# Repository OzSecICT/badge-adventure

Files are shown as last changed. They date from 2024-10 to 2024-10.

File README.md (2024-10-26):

# OzSec 2024 Adventure Badge

This repo contains the code and KiCad files to design the OzSec 2024 badge. 

## Theme

The theme of this year's badge is 'Light The Badge' where the front of the badge has LEDs representing various cities. In the default mode it will be twinkly and randomly blink the LEDs. 

When you connect to the badge via a serial console, a text-based adventure RPG will be playable. Each city in the game is represented by an LED, and each city will have a quest that needs to be completed. 

Once you complete each city's quest, that LED will light up. You need to light up every city in order to unlock access to Wichita and change the RGB LED. Completing that ultimate quest will reveal a CTF flag and change the RGB LED to green. 

## Codebase

The badge is based on an ESP32-S3 using the Arduino framework. This repo is designed to be opened in VS Code with the PlatformIO extension. 

### Files

Brief overview of the files and what they do:

**include/config.hpp:**
- Tracks the currently developed version for use with updates over the web. 
- WiFi SSID and Password defaults.

**include/ozsec/update.hpp and src/ozsec/update.cpp:**
- Manages over the air updates.
- Triggered by holding boot button in `main.cpp`

**includes/ozsec/ble.hpp and src/ozsec/ble.hpp:**
- Bluetooth Low Energy config, searches for an advertisement from an OzSec 2023: S1M0N badge. Sets a variable once a badge advertisement is found and stops searching.

**includes/ozsec/lights.hpp and src/ozsec/lights.cpp:**
- Manages the LEDs and NeoPixel RGB LED
- `Lights::twinkle()` is the main function that is called by `Adventure::bgloop()` on the second core in `main.cpp` to twinkle the lights when not in the game.

**src/main.cpp:**
- Main arduino `setup()` and `loop()` functions that call other class functions. 
- Sets up buttons using the OneButton library.
- Manages persistent data and game/badge states using the Preferences library.

**includes/ozsec/buttons.hpp:**
- Centralized setup of the buttons using OneButton

**includes/ozsec/rooms.hpp:**
- Room configs for the text based adventure

**includes/ozsec/npcs.hpp:**
- NPC config for the text based adventure

**includes/ozsec/adventure.hpp and src/ozsec/adventure.cpp:**
- The main text based adventure game.
- Manages character and badge states, what lights are lit, flags unlocked, etc.

### Wi-Fi setup
You can either set the wifi credentials in `config.hpp` or you can launch into the text game and enter `wifi` command to set it on your badge specifically.

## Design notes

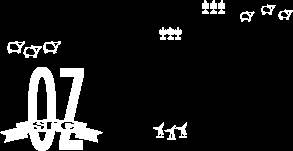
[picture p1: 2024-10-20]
kicad/ozsec-2024/Asset 7.png

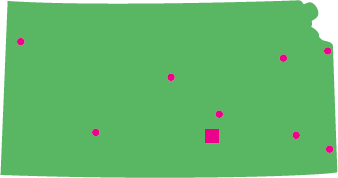
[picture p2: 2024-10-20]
kicad/ozsec-2024/LED Placement.png

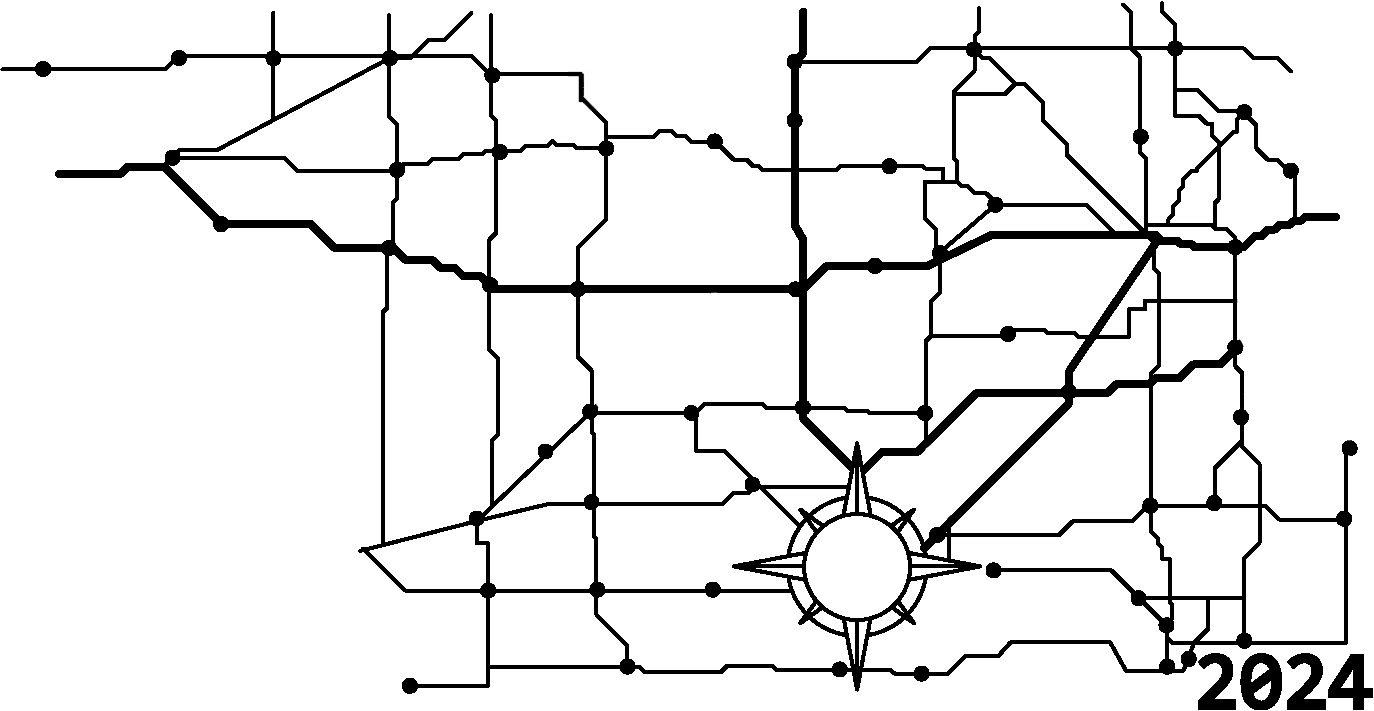
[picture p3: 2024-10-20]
kicad/ozsec-2024/Copper_Modified.png

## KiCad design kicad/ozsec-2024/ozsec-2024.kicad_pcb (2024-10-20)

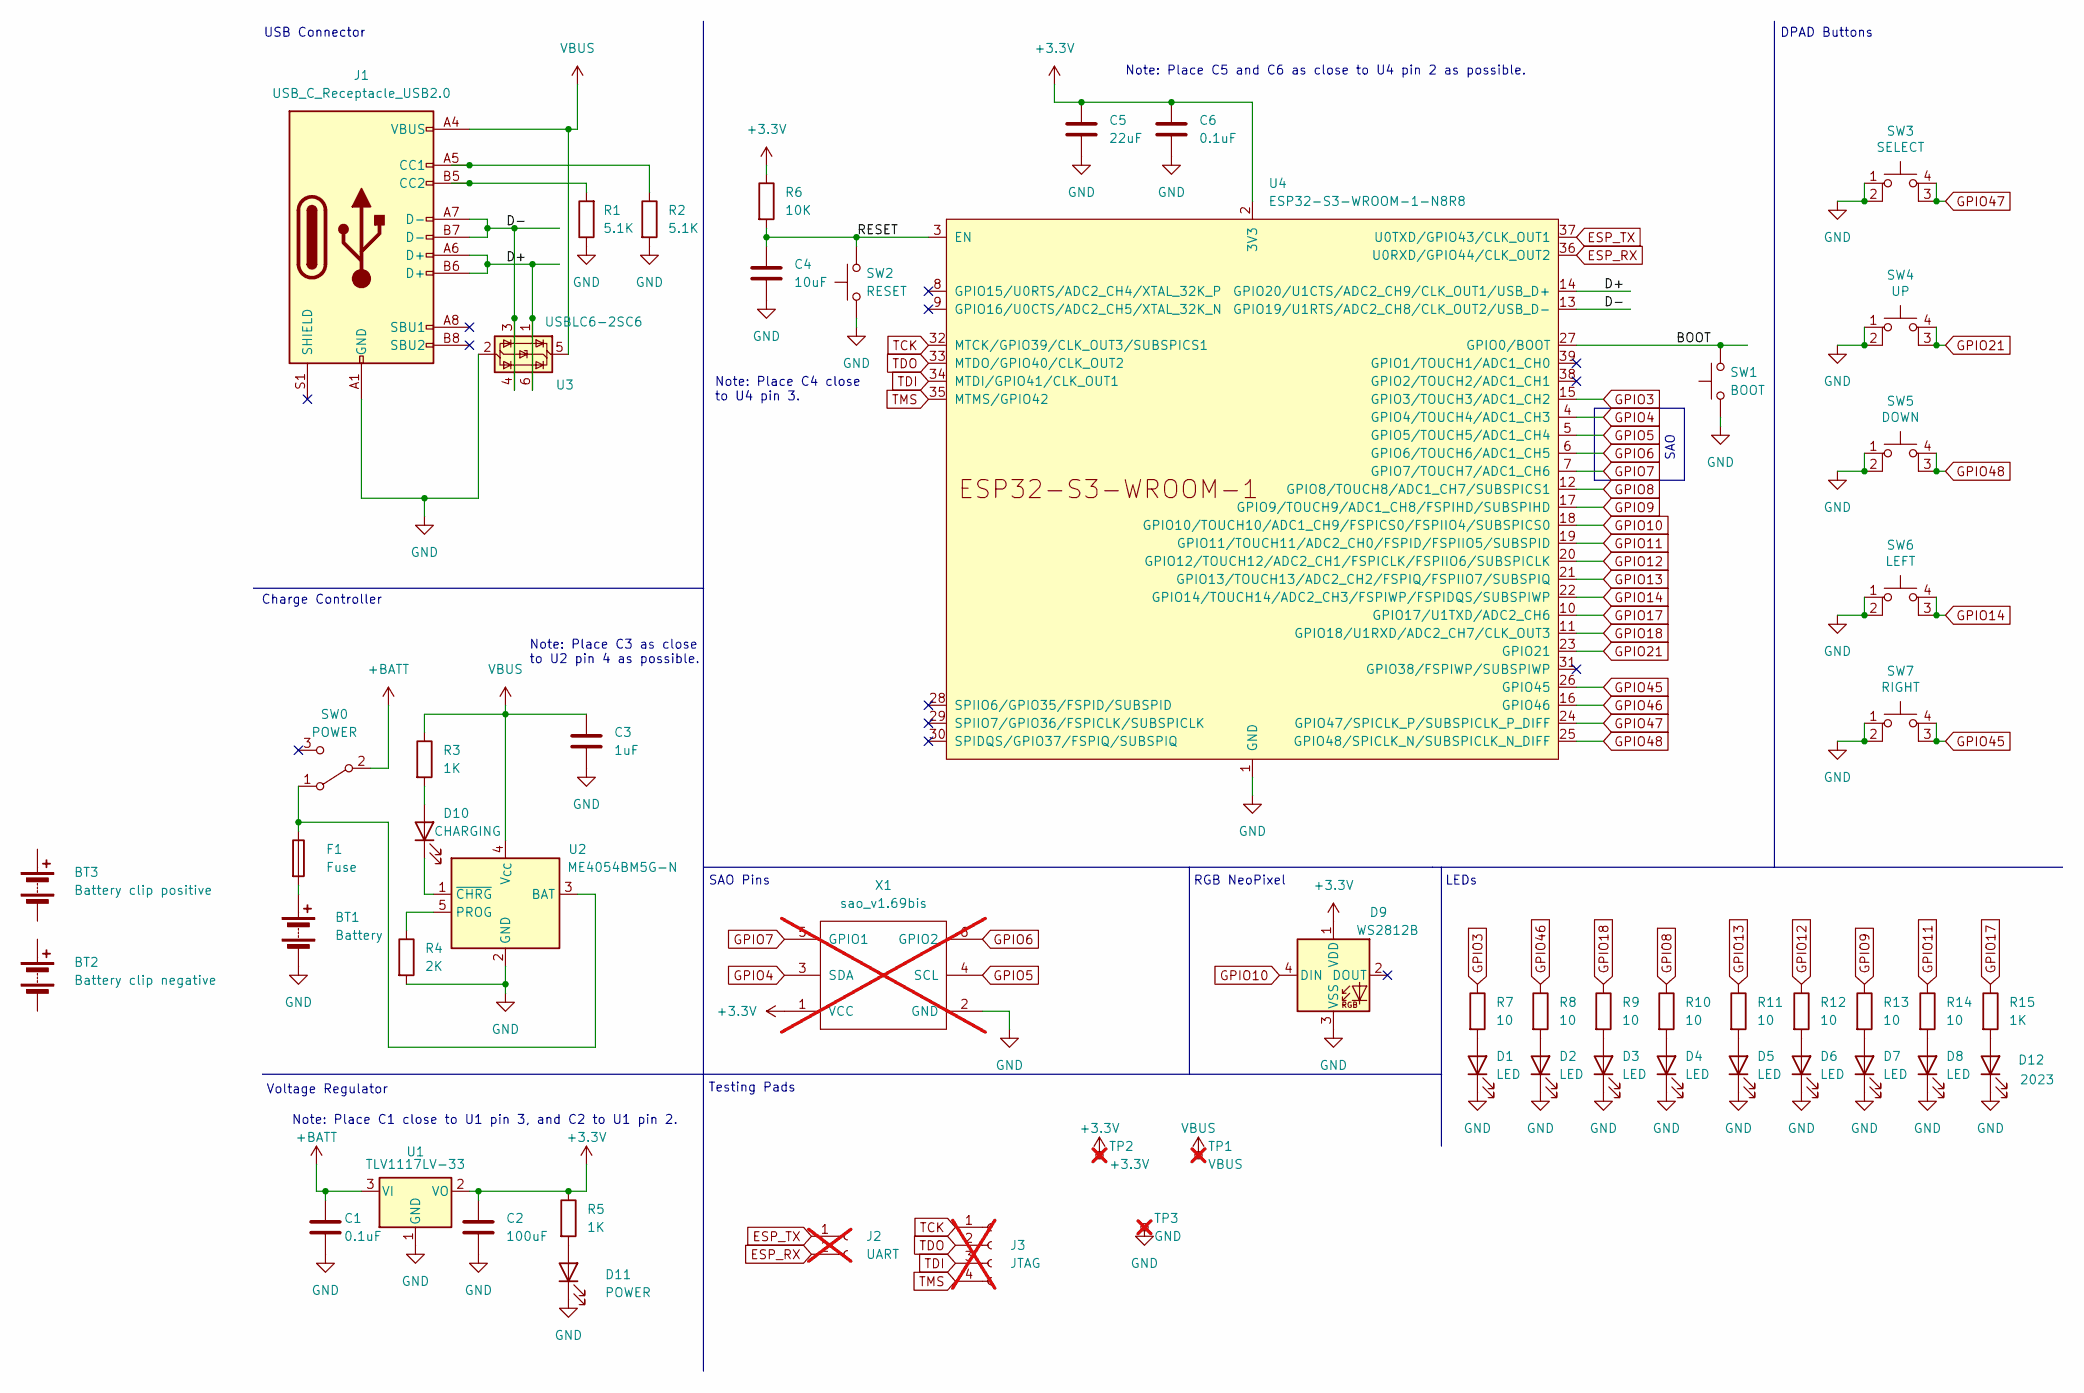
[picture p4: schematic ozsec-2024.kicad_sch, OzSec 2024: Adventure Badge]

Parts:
BT1: Battery; MY-AA-04_Silkscreen_Only; LCSC C2979179
BT2: Battery clip negative; MY-AA-04_Negative; LCSC C2979179
BT3: Battery clip positive; MY-AA-04_Positive; LCSC C2979179
C1, C6: 0.1uF; C_0402_1005Metric; LCSC C1525
C2: 100uF; C_1206_3216Metric; LCSC C15008
C3: 1uF; C_0402_1005Metric; LCSC C52923
C4: 10uF; C_0805_2012Metric; LCSC C15850
C5: 22uF; C_0805_2012Metric; LCSC C45783
D1, D2, D3, D4, D5, D6, D7, D8: LED; LED_0805_2012Metric_Pad1.15x1.40mm_HandSolder; LCSC C34499
D9: WS2812B; LED_WS2812B_PLCC4_5.0x5.0mm_P3.2mm; LCSC C2843785
D10: CHARGING; LED_0805_2012Metric_Pad1.15x1.40mm_HandSolder; LCSC C2296
D11: POWER; LED_0805_2012Metric_Pad1.15x1.40mm_HandSolder; LCSC C2297
D12: 2023; LED_0805_2012Metric_Pad1.15x1.40mm_HandSolder; LCSC C2297
F1: Fuse; Fuse_1206_3216Metric; LCSC C261957
J1: USB_C_Receptacle_USB2.0; USB_C_Receptacle_G-Switch_GT-USB-7010ASV; LCSC C2988369
J2: UART; PinHeader_1x02_P2.54mm_Vertical; not fitted
J3: JTAG; PinHeader_1x04_P2.54mm_Vertical; not fitted
R1, R2: 5.1K; R_0805_2012Metric; LCSC C27834
R3, R5, R15: 1K; R_0805_2012Metric_Pad1.20x1.40mm_HandSolder; LCSC C17513
R4: 2K; R_0805_2012Metric; LCSC C17604
R6: 10K; R_0805_2012Metric; LCSC C17414
R7, R8, R9, R10, R11, R12, R13, R14: 10; R_0805_2012Metric; LCSC C17415
SW0: POWER; SW_SPDT_PCM12; LCSC C431541
SW1: BOOT; SW_Push_1P1T_XKB_TS-1187A; LCSC C318884
SW2: RESET; SW_Push_1P1T_XKB_TS-1187A; LCSC C318884
SW3: SELECT; SW_SMD_TSC015XXXXXXX; LCSC C2888900
SW4: UP; SW_SMD_TSC015XXXXXXX; LCSC C2888900
SW5: DOWN; SW_SMD_TSC015XXXXXXX; LCSC C2888900
SW6: LEFT; SW_SMD_TSC015XXXXXXX; LCSC C2888900
SW7: RIGHT; SW_SMD_TSC015XXXXXXX; LCSC C2888900
TP1: VBUS; TestPoint_Pad_D1.5mm; not fitted
TP2: +3.3V; TestPoint_Pad_D1.5mm; not fitted
TP3: GND; TestPoint_Pad_1.5x1.5mm; not fitted
U1: TLV1117LV-33; SOT-223; LCSC C15578
U2: ME4054BM5G-N; TSOT-23-5; LCSC C478383
U3: USBLC6-2SC6; SOT-23-6; LCSC C2827654
U4: ESP32-S3-WROOM-1-N8R8; ESP32-S3-WROOM-1; LCSC C2913201
X1: sao_v1.69bis; Badgelife-SAOv169-BADGE-2x3; not fitted

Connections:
+3.3V: C2.1, C5.1, C6.1, D9.1 (VDD), R5.1, R6.1, TP2.1, U1.2 (VO), U1.4, U4.2 (3V3), X1.1 (VCC)
+BATT: C1.1, SW0.2 (B), U1.3 (VI)
/BOOT: SW1.2, U4.27 (GPIO0/BOOT)
/D+: J1.A6 (D+), J1.B6 (D+), U3.1 (I/O1), U3.6 (I/O1), U4.14 (GPIO20/U1CTS/ADC2_CH9/CLK_OUT1/USB_D+)
/D-: J1.A7 (D-), J1.B7 (D-), U3.3 (I/O2), U3.4 (I/O2), U4.13 (GPIO19/U1RTS/ADC2_CH8/CLK_OUT2/USB_D-)
/RESET: C4.1, R6.2, SW2.2, U4.3 (EN)
ESP_RX: J2.2, U4.36 (U0RXD/GPIO44/CLK_OUT2)
ESP_TX: J2.1, U4.37 (U0TXD/GPIO43/CLK_OUT1)
GND: BT1.2 (-), BT2.2 (-), C1.2, C2.2, C3.2, C4.2, C5.2, C6.2, D1.1 (K), D2.1 (K), D3.1 (K), D4.1 (K), D5.1 (K), D6.1 (K), D7.1 (K), D8.1 (K), D9.3 (VSS), D11.1 (K), D12.1 (K), J1.A1 (GND), J1.A12 (GND), J1.B1 (GND), J1.B12 (GND), R1.1, R2.2, R4.2, SW1.1, SW2.1, SW3.1, SW3.2, SW4.1, SW4.2, SW5.1, SW5.2, SW6.1, SW6.2, SW7.1, SW7.2, TP3.1, U1.1 (GND), U2.2 (GND), U3.2 (GND), U4.1 (GND), U4.40 (GND), U4.41 (GND), X1.2 (GND)
GPIO3: R7.1, U4.15 (GPIO3/TOUCH3/ADC1_CH2)
GPIO4: U4.4 (GPIO4/TOUCH4/ADC1_CH3), X1.3 (SDA)
GPIO5: U4.5 (GPIO5/TOUCH5/ADC1_CH4), X1.4 (SCL)
GPIO6: U4.6 (GPIO6/TOUCH6/ADC1_CH5), X1.6 (GPIO2)
GPIO7: U4.7 (GPIO7/TOUCH7/ADC1_CH6), X1.5 (GPIO1)
GPIO8: R10.1, U4.12 (GPIO8/TOUCH8/ADC1_CH7/SUBSPICS1)
GPIO9: R13.1, U4.17 (GPIO9/TOUCH9/ADC1_CH8/FSPIHD/SUBSPIHD)
GPIO10: D9.4 (DIN), U4.18 (GPIO10/TOUCH10/ADC1_CH9/FSPICS0/FSPIIO4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)
GPIO11: R14.1, U4.19 (GPIO11/TOUCH11/ADC2_CH0/FSPID/FSPIIO5/S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)
GPIO12: R12.1, U4.20 (GPIO12/TOUCH12/ADC2_CH1/FSPICLK/FSPIIO6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)
GPIO13: R11.1, U4.21 (GPIO13/TOUCH13/ADC2_CH2/FSPIQ/FSPIIO7/S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)
GPIO14: SW6.3 (K), SW6.4 (A), U4.22 (GPIO14/TOUCH14/ADC2_CH3/FSPIWP/FSPIDQS/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)
GPIO17: R15.1, U4.10 (GPIO17/U1TXD/ADC2_CH6)
GPIO18: R9.1, U4.11 (GPIO18/U1RXD/ADC2_CH7/CLK_OUT3)
GPIO21: SW4.3 (K), SW4.4 (A), U4.23 (GPIO21)
GPIO45: SW7.3 (K), SW7.4 (A), U4.26 (GPIO45)
GPIO46: R8.1, U4.16 (GPIO46)
GPIO47: SW3.3 (K), SW3.4 (A), U4.24 (GPIO47/SPICLK_P/SUBSPICLK_P_DIFF)
GPIO48: SW5.3 (K), SW5.4 (A), U4.25 (GPIO48/SPICLK_N/SUBSPICLK_N_DIFF)
unnamed: D1.2 (A), R7.2
unnamed: D2.2 (A), R8.2
unnamed: D3.2 (A), R9.2
unnamed: D4.2 (A), R10.2
unnamed: D5.2 (A), R11.2
unnamed: D6.2 (A), R12.2
unnamed: D7.2 (A), R13.2
unnamed: D8.2 (A), R14.2
unnamed: D10.2 (A), R3.2
unnamed: D10.1 (K), U2.1 (~CHRG)
unnamed: D11.2 (A), R5.2
unnamed: D12.2 (A), R15.2
unnamed: J1.A5 (CC1), R2.1
unnamed: J1.B5 (CC2), R1.2
unnamed: F1.1, SW0.1 (A), U2.3 (BAT)
unnamed: R4.1, U2.5 (PROG)
TCK: J3.1, U4.32 (MTCK/GPIO39/CLK_OUT3/SUBSPICS1)
TDI: J3.3, U4.34 (MTDI/GPIO41/CLK_OUT1)
TDO: J3.2, U4.33 (MTDO/GPIO40/CLK_OUT2)
TMS: J3.4, U4.35 (MTMS/GPIO42)
VBUS: C3.1, J1.A4 (VBUS), J1.A9 (VBUS), J1.B4 (VBUS), J1.B9 (VBUS), R3.1, TP1.1, U2.4 (V_{CC}), U3.5 (VBUS)

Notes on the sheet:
Testing Pads
USB Connector
Note: Place C5 and C6 as close to U4 pin 2 as possible.
DPAD Buttons
Voltage Regulator
SAO
Note: Place C3 as close to U2 pin 4 as possible.
Note: Place C4 close to U4 pin 3.
RGB NeoPixel
SAO Pins
Charge Controller
Note: Place C1 close to U1 pin 3, and C2 to U1 pin 2.
LEDs

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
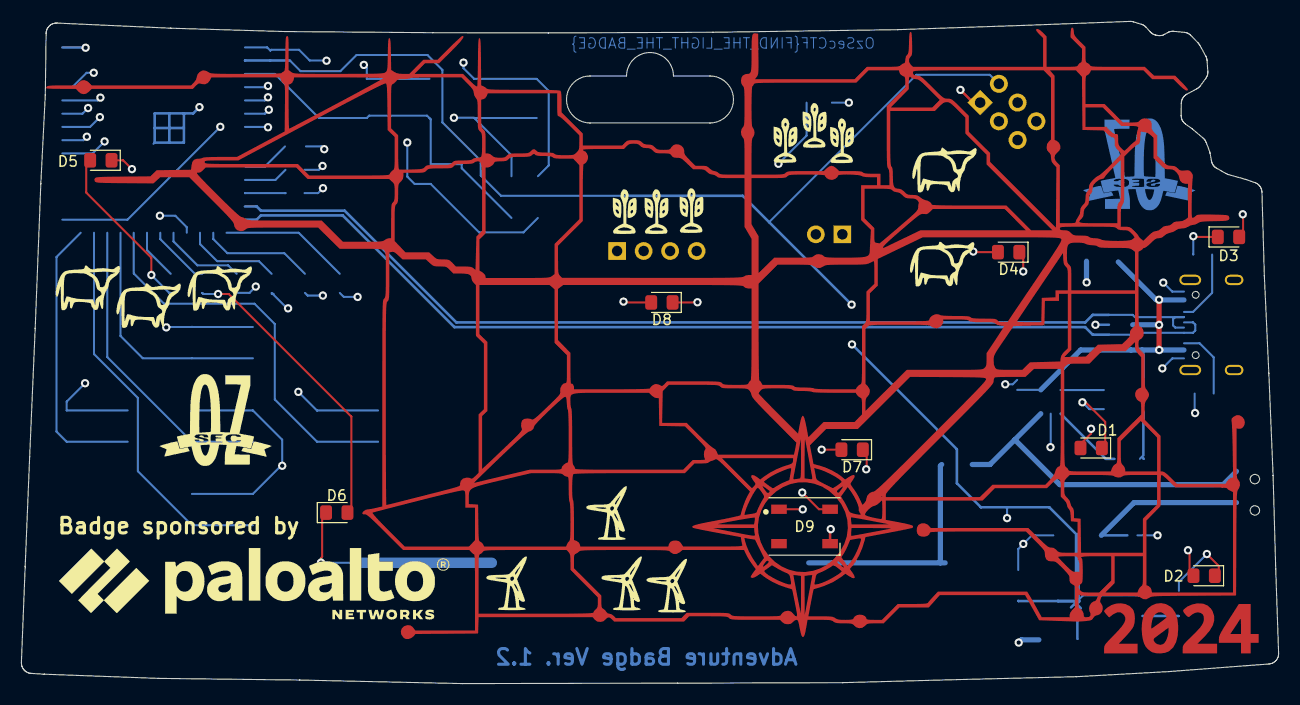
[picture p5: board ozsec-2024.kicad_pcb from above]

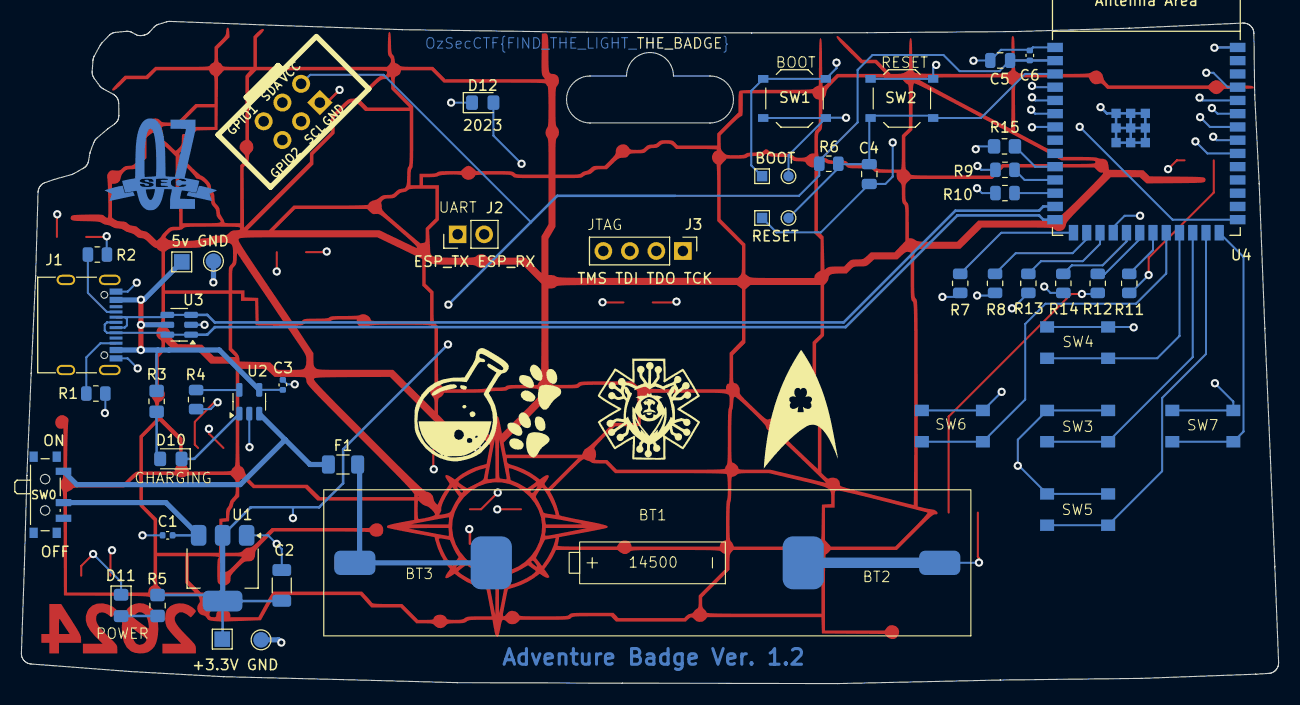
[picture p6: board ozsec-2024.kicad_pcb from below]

Board: 4 copper layers, 120.5 x 63.5 mm, 53 parts (43 on the bottom side), 50 nets.

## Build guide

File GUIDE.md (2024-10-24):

# OzSec 2024: Adventure Badge

This guide walks you through collecting all of the CTF flags within the game.

## Connecting to the Game

In order to play the text based adventure on your OzSec 2024 badge, you will need to connect to the serial console of the badge via USB.

- Power on the badge if needed by flipping the power switch on the bottom of the badge, by the USB port, away from the usb port.
> Note that it must be a data USB-C cable, not a power only cable. If you don't see a COM port for your badge, and installing drivers doesn't help, try a different cable.

Visit [Serial Terminal by Spacehuhn](https://serial.huhn.me/) in Chrome, Edge, or Opera from a desktop PC.

Click the green Connect button.

In the browser popup, select the USB Serial (COM#) and then click Connect

The serial terminal will load, and you will see the serial output from your badge.

If needed, reset your badge by pressing the RESET button on the top right hand side of your badge.

## The Training Area

The training area is intended to get you familiar with the commands and options avialable to you within the game. 

You start off in the Training Tent where you can talk to a Non-Player Character (NPC) and read a paper with some instructions. When you're ready to leave, you can use your navigation commands to exit to the west.

In the Great Outdoors you will find an item on the ground that you can pick up, and a button that will transport you to the main game. 

You will need to speak to the NPC here and let him know you are ready to leave in order for the button to work. 

Before you leave, speak to Bob and if you follow the right dialog tree he will give you your first flag. You can head north and enter the vault to pick up your second flag. 

After heading north, `unlock` the vault door with the key you picked up outside. Enter and you can pick up the second flag. 

Now that you have the flags, head back outside and let Bob know you are ready to leave, then hit the button to be transported.

## Kansas City

Welcome to Kansas City! You wake up on a bus in the maintenance garage and need to get a ticket out of here. You can get a ticket after helping get their buses back online. 

You will need to repair each bus in the garage before returning to the manager to get a ticket. 

Before you leave, make sure you pick up the slice of cheese for a flag from the break room. 

## Topeka

Topeka's local hospital is having a cyber incident, you need to help them collect some drives from PC's to perform incident response analysis on. 

Find the hospital off of I-70. Pull the drives from the five PC's scattered around the hospital complex, and don't forget to grab a box of donuts from the break room!

While you're exploring, you will find a Raspnberry Pi in a networking closet, if you take that to the manager of the incident response firm you can place it with his collection of Pi's for a flag. 

Bring the box of donuts and the five drives to the conference room in the hospital to get two flags and complete this area.

Head you can head west to Ellsworth, or South to Chanute. 

You can travel to Wichita if you want to go to another city, but Wichita itself is currently off limits until you complete all other towns. 

## Chanute

Chanute has a reporter writing a story on the city. He heard that there was a brief time that Chanute had a differnet name, help him find the alternative name for the city. 

This area has only the one flag, but there are a few other actions you can perform like picking up some coffee. 

To complete this area, head to the Town Hall, and go out their back exit into the alleyway. There you will find a sign with the name that the city used to have. Bring this to the reporter in the town hall to complete.

From here you can head down to Pittsburg by heading to the southeast corner of the map.

## Pittsburg

The city network is experiencing some issues, and the Town Hall needs to get some information to the court house. Stop by Town Hall and pick up a letter, deliver it to the Court House for a flag. 

While you're heading into town, stop by the local flower shop and coffee shop to pick up a flower and coffee that needs to be delivered. 

The coffee was ordered by someone waiting in the court house, go deliver that for a flag. While you're there, deliver the letter from the Town Hall for another flag. 

Make note of the network closet in the back of the court house, you can pick up a flash drive from the local park and try plugging it in! Probably not a great idea, but hey it gets you a flag!

To complete this area you will need to visit the local university and help them get their computer lab back online. 

Grab a ladder from one of the classrooms and hop over the wall through the ceiling tiles to get into the computer lab.

Once you're in the computer lab, shutdown and unplug the random computer there. 

To finish this up, go back to the town hall and ask the receptionist to try it again, as their network should be back online now for the final flag. 

## Ellsworth

The water supply in Ellsworth is having some issues with quality. Stop by the water plant on the east side of town and see if you can help them fix their issues. 

You will need to get permission to access the water plant, so before you head there stop by the water company offices on the main street of town and grab an access card. 

While you're out exploring the city, find and stop by the post office to pick up a package and a flag. 

After you have the keycard, visit the water plant and check in with security. They will let you in where you can test the quality of the water and restore the chemical levels to normal levels. 

But first you need to find out why your changes keep getting reverted. If you check the network closet there is an unknown PC there. Unplug it and you can now restore water levels, check the quality, and report your findings to the operator. This will complete the town and light your badge, and give you a flag.

Before you head out of down, grab a soda from one of the shops and give it to the groundskeeper in the park for a flag.

## Goodland

Goodland has been overrun by robot taxis! Sadly, they have begun breaking down and causing all sorts of issues for the locals. 

You can help fix them by visiting a local auto shop and picking up a key to the taxi, then going to the telecom provider in town and picking up a usb key to re-flash the taxi firmware. 

There are five taxi's stuck around the city, the first one you should have seen when you first netered town. Another one is further to the west from the auto shop, and the rewst are up north near the airport and faire. 

While you're helping the taxi's, pick up a plane ticket for a flag at the airport, and visit the fair for a turkey leg with another flag on it. 

From here you can head down to Dodge City, or to Ellsworth. 

## Dodge City

As you enter Dodge City, there's a Flipper Zero laying on the ground, make sure and pick that up as it's needed. You'll be freeing 'The Associate' and you need to clone some keycards to do that. 

After you are armed with a Fllipper, visit the local saloon and clone the sherrif's keycard while he's busy. While you're in there stop by the bar and pick up a drink, or head over to the local gas station and pick up an energy drink.

On your way to the sherrif's office enter the game room of the saloon and offer the player a drink for a flag. When you get to the sherrifs office head into the jail and replay the sherrifs keycard to free the associate. 

Next head down to the train station and clone the keycard of the train operator on your way, this will allow you to unlock the train car for another flag. 

As you exit town via the train, your final flag will be revealed and this city will light up o your badge.

## Newton

The college in Newton has suffered a cyber incident that took their systems down. Thankfully they have proper disaster recovery documentation and recovery instrucitons. 

Unfortunately, they seem to have misplaced the documents. Can you help collect the 4 pages of the DR document and help their IT guy get systems back online? 

Search through the college campus to find the recovery documents. You will find a USB drive in the parking lot on your way there, pick it up for a flag when you insert it into their server. Maybe don't do that in real life.. but this is just a game, right?

While you're searching for the recovery documents, grab some lunch for the poor IT guy, he's working really hard. 

Return lunch and the recovery documents to the IT guy in the campus and be rewarded with the flag and this city is completed. 

Next, head over to Wichita to complete the final quests!

## Wichita

Once you've completed all the other towns and on your badge their lights are lit, you can enter Wichita. 

Wichita has two main quests, the water company and the airport. If you visit the water company in the northern side of town you be tasked with visiting a local bank branch to pick up a backup tape so they can restore from backups.

Return to the IT manager and let him you know you have the tape and he will give you a key to the datacenter. Go across the hall to the datacenter and load the tapes. Return to the manager to let him know for your first flag. 

The aiport has suffered from a vendor's incident that has taken their computers offline. You will need to visit the IT guy in the food court, and pick up a flash drive that will auto-reboot and fix the PC's. 

Once you have the drive, go around the airport rebooting each of the five PC's. You will need to pick up some keys from the janitors closet on the east side of the airport, and unlock the closet on the west side to get the final PC. Don't forget to check the TSA line for one of the PC's that needs rebooted. 

After completing both the water company and airport quests you will complete the main quests of Wichita, and the RGB LED on your badge should turn green, congratulations!

You can pick up a phamplhet from the bank's loan office and give it to a farmer inthe farmers market for a flag.

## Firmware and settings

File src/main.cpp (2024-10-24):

#include <Arduino.h>
#include <OneButton.h>
#include <Preferences.h>

#include <ozsec/adventure.hpp>
#include <ozsec/ble.hpp>
#include <ozsec/update.hpp>
#include <ozsec/lights.hpp>
#include <ozsec/buttons.hpp> // Setup buttons
#include <config.hpp>

Preferences preferences;
Adventure adventure;
OzSecBLE ozsecBLE;
extern bool bleInit;

String wifiSsid;
String wifiPassword;

// Setup background loop running on core 0, main loop() runs on core 1
TaskHandle_t BackgroundTask;              // Variable to hold the background task handle
void BackgroundTaskCode(void *parameter); // Function prototype for the background task

void setup()
{
    Serial.begin(115200);
    bleInit = false;
    Lights::init();
    preferences.begin("badge-state", false);

    // Set initial badge details. Not realy used at the moment, but maybe later.
    if (!(preferences.isKey("badge") && preferences.getString("badge") != "Adventure"))
    {
        preferences.putString("badge", "Adventure");
    }
    if (!(preferences.isKey("event") && preferences.getString("event") != "OzSec 2024"))
    {
        preferences.putString("event", "OzSec 2024");
    }
    if (!(preferences.isKey("version") && preferences.getString("version") != "Final-2.0"))
    {
        preferences.putString("version", "Final-2.0");
    }

    // Setup default wifi creds
    if (preferences.isKey("wifiSsid"))
    {
        wifiSsid = preferences.getString("wifiSsid");
    }
    else
    {
        wifiSsid = WIFI_SSID;
    }

    if (preferences.isKey("wifiPassword"))
    {
        wifiPassword = preferences.getString("wifiPassword");
    }
    else
    {
        wifiPassword = WIFI_PASSWORD;
    }

    // Print some badge info to serial
    Serial.printf("Badge: %s \r\nEvent: %s \r\nVersion: %s \r\n", preferences.getString("badge").c_str(), preferences.getString("event").c_str(), preferences.getString("version").c_str());
    preferences.end();
    // Setup OneButton functions to call when a button is pressed
    // Set up long press on BOOT to OTA
    boot_button.setPressMs(1500);
    boot_button.attachLongPressStart([]()
                                     {
        Serial.println("Starting OTA update...");
        Update::checkForUpdate(); }); // Call the OTA update function

    select_button.attachClick([]()
                              {
        adventure.processPromptResponse("select");; });
    boot_button.attachClick([]()
                            {
        adventure.processPromptResponse("boot");; });
    up_button.attachClick([]()
                          { adventure.processPromptResponse("n"); });
    right_button.attachClick([]()
                             { adventure.processPromptResponse("e"); });
    left_button.attachClick([]()
                            { adventure.processPromptResponse("w"); });
    down_button.attachClick([]()
                            { adventure.processPromptResponse("s"); });

    // Adventure initialization code
    adventure.init();

    // Background task stuff.
    xTaskCreatePinnedToCore(
        BackgroundTaskCode, /* Function to run the task */
        "BackgroundTask",   /* Name of the task */
        10000,              /* Stack size in words */
        NULL,               /* Task input parameter */
        0,                  /* Priority of the task */
        &BackgroundTask,    /* Task handle. */
        0);                 /* Core where the task should run */
}

void loop()
{

    // Run any relevant adventure loop code
    adventure.loop();

    // Button ticks to register presses. Part of the OneButton library.
    boot_button.tick();
    select_button.tick();
    up_button.tick();
    down_button.tick();
    left_button.tick();
    right_button.tick();
}

// This function runs on core 0 and is used to run background
// tasks to not interfer with the main loop code.
void BackgroundTaskCode(void *parameter)
{
    while (true)
    {
        // Run any relevant adventure loop code
        adventure.bgloop();
    }
}

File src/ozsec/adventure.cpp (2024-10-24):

#include <ozsec/adventure.hpp>
#include <ozsec/lights.hpp>
#include <ozsec/ble.hpp>

// Player and game state variables
CharacterState player;
GameState game;

// Callbacks are used so we don't block while waiting for text input.
Callback storedCallback;
PromptCallback promptCallback;
TalkCallback talkCallback;

// Track if the serial is connected, and if the prompt should be shown.
bool serialConnected;
bool showPrompt;

LightMode lightMode = TWINKLE;

String konamiStrings[10] = {"n", "n", "s", "s", "w", "e", "w", "e", "boot", "select"};
int konamiIndex;
#define KONAMI_INDEX_MAX 10

/// @brief Initialize the game state and load saved data.
void Adventure::init()
{
    // Load game data
    load();

    printHelp();

    // Default states
    serialConnected = false;
    showPrompt = true;

    // Set the initial callback to display the room
    setCallback(&Adventure::displayRoom);
}

/// @brief Main game loop
void Adventure::loop()
{
    // Print "Press enter" every 5 seconds until we know serial is connected
    static unsigned long lastPrint = 0;
    if (!serialConnected && millis() - lastPrint > 5000)
    {
        printHelp();
        lastPrint = millis();
    }

    if (!serialConnected && Serial.available() > 0)
    {
        // Serial is connected, clear the input buffer
        while (Serial.available() > 0)
        {
            Serial.read();
        }

        serialConnected = true;
        if (lightMode == TWINKLE)
        {
            lightMode = ADVENTURE;
        }
        Serial.println("Starting serial console...\n\n");
    }

    if (serialConnected)
    {
        // Show will display what is needed based on the callback set.
        show();

        // Handle anything that needs done in the background
        stateUpdate();

        // Prompt for input
        prompt();
    }
}

/// @brief This loop runs on core 0 along with the BLE scan.
/// This loop will be delayed periodically during BLE scans.
void Adventure::bgloop()
{
    // Handle LED mode
    switch (lightMode)
    {
    case TWINKLE:
        Lights::twinkle();
        if (ledTwinkleMode != 2)
        {
            if (game.qwichita)
            {
                Lights::stripOn(CRGB(0, 255, 0), 25);
            }
            else
            {
                Lights::stripOn(CRGB(255, 0, 0), 25);
            }
        }
        break;
    case ADVENTURE:
        ledMap();
        delay(1000);
        break;
    }
}

/// @brief Handles the LEDs when in ADVENTURE mode.
void Adventure::ledMap()
{
    if (game.qmodel2023)
    {
        // Turn on the LED
        digitalWrite(all_leds[0], HIGH);
    }
    else
    {
        // Turn off the LED
        digitalWrite(all_leds[0], LOW);
    }

    // Chanute
    if (game.qchanute)
    {
        Lights::ledOn(all_leds[1], false);
    }
    else
    {
        Lights::ledOff(all_leds[1], false);
    }

    // Pittsburgh
    if (game.qpittsburg)
    {
        Lights::ledOn(all_leds[2], false);
    }
    else
    {
        Lights::ledOff(all_leds[2], false);
    }

    // Kansas City
    if (game.qkansascity)
    {
        Lights::ledOn(all_leds[3], false);
    }
    else
    {
        Lights::ledOff(all_leds[3], false);
    }

    // Topeka
    if (game.qtopeka)
    {
        Lights::ledOn(all_leds[4], false);
    }
    else
    {
        Lights::ledOff(all_leds[4], false);
    }

    // Goodland
    if (game.qgoodland)
    {
        Lights::ledOn(all_leds[5], false);
    }
    else
    {
        Lights::ledOff(all_leds[5], false);
    }

    // Dodge City
    if (game.qdodgecity)
    {
        Lights::ledOn(all_leds[6], false);
    }
    else
    {
        Lights::ledOff(all_leds[6], false);
    }

    // Newton
    if (game.qnewton)
    {
        Lights::ledOn(all_leds[7], false);
    }
    else
    {
        Lights::ledOff(all_leds[7], false);
    }

    // Ellsworth
    if (game.qellsworth)
    {
        Lights::ledOn(all_leds[8], false);
    }
    else
    {
        Lights::ledOff(all_leds[8], false);
    }

    // Wichita
    if (game.qwichita)
    {
        // Turn on RGB strip
        Lights::stripOn(CRGB(0, 255, 0), 25);
    }
    else
    {
        // Keep RGP strip red
        Lights::stripOn(CRGB(255, 0, 0), 25);
    }
}

/// @brief Print help message to the serial console.
void Adventure::printHelp()
{
    Serial.println("\n\nHold BOOT to start OTA firmware update.");
    Serial.println("");
    Serial.println("Press enter to activate the serial console.");
}

/// @brief Load game and player state from memory.
void Adventure::load()
{
    // Keep in sync with Adventure::save()
    preferences.begin("game-data", false);
    // Load game state from memory, with default values if not set.
    game.playing = false;
    game.message = "";
    game.cheats = false;

    // Quest data
    game.qmodel2023 = preferences.getBool("qmodel2023", false);
    game.qtrainingvault = preferences.getBool("qtrainingvault", false);
    game.qtraining = preferences.getBool("qtraining", false);
    game.qchanute = preferences.getBool("qchanute", false);
    game.qpittsburg = preferences.getBool("qpittsburg", false);
    game.qkansascity = preferences.getBool("qkansascity", false);
    game.qtopeka = preferences.getBool("qtopeka", false);
    game.qgoodland = preferences.getBool("qgoodland", false);
    game.qdodgecity = preferences.getBool("qdodgecity", false);
    game.qnewton = preferences.getBool("qnewton", false);
    game.qellsworth = preferences.getBool("qellsworth", false);
    game.qwichita = preferences.getBool("qwichita", false);

    // Load player data
    player.name = preferences.getString("playername", "User");
    player.room = preferences.getInt("playerroom", TRAININGTENT);
    player.previousRoom = preferences.getInt("playerroom", TRAININGTENT);
    player.npc = -1; // -1 means no NPC is being talked to
    player.dialogIndex = 0;
    player.notebook = preferences.getString("playernotebook", "Your notebook has the following entries:\r\n\r\n");
    player.beacon = preferences.getInt("playerbeacon", 1);
    preferences.end();

    // Player inventory is handled by the game-data-inventory preference namespace
    preferences.begin("game-data-inventory", true);
    bool inventoryInit = preferences.isKey("INIT");
    if (inventoryInit == false)
    {
        preferences.end();
        preferences.begin("game-data-inventory", false);
        preferences.putBool("INIT", true);
        for (int i = 0; i < INVENTORY_ITEM_INDEX_COUNT; i++)
        {
            preferences.putInt(InventoryItems[i], 0);
            player.inventory[i] = 0;
        }
        preferences.end();
        preferences.begin("game-data-inventory", true);
        addItem(INVENTORY_ITEM_LANTERN);
        addItem(INVENTORY_ITEM_MAP);
    }

    konamiIndex = 0;
}
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
